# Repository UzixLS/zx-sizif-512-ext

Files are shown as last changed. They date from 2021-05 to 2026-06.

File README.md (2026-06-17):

## Sizif-512 extension

Extension board for [Sizif-512](https://github.com/UzixLS/zx-sizif-512).



### Features
* Turbo Sound FM
* General Sound (12MHz / 512Kb RAM)
* SAA1099
* MIDI sound

### Changelog & current status
* Rev.A - first release. Please note the [errata](pcb/rev.A/ERRATA.txt).
* Rev.A1 - fixed all known issues of rev.A. Please note the [errata](pcb/rev.A1/ERRATA.txt).

### Related projects
* Turbo Sound FM ([link](http://www.nedopc.com/TURBOSOUND/ts-fm.php))
* ZXM-SoundCard ([link](http://micklab.ru/My%20Soundcard/ZXMSoundCard.htm))
* ZXM-GeneralSound ([link](http://micklab.ru/My%20Soundcard/ZXMGeneralSound.htm))

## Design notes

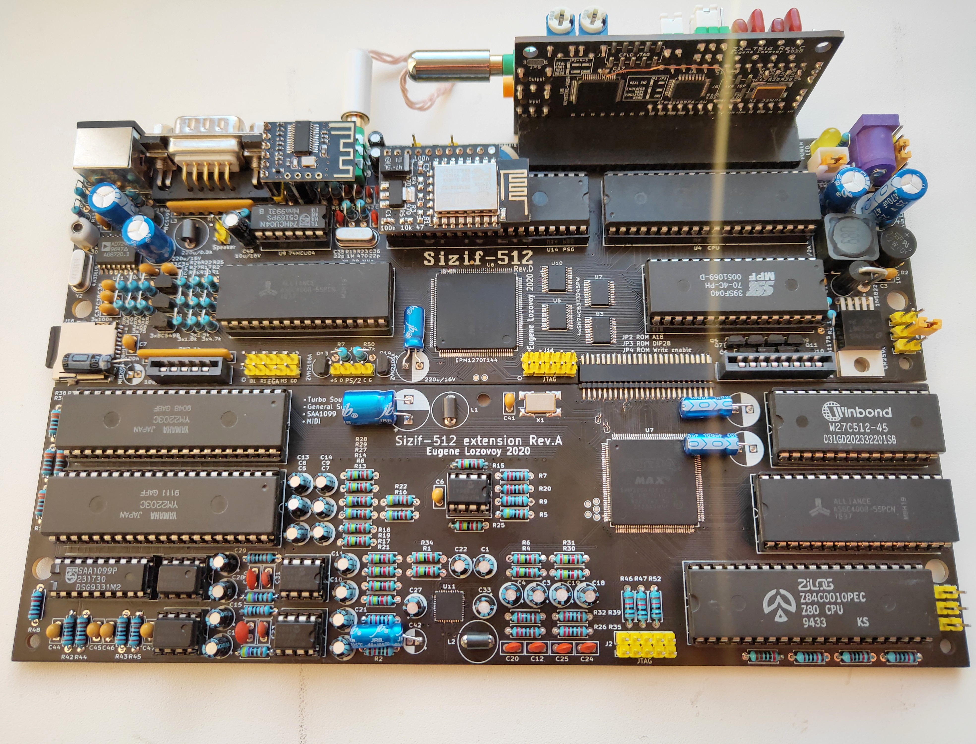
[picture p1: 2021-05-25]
images/revA.jpg

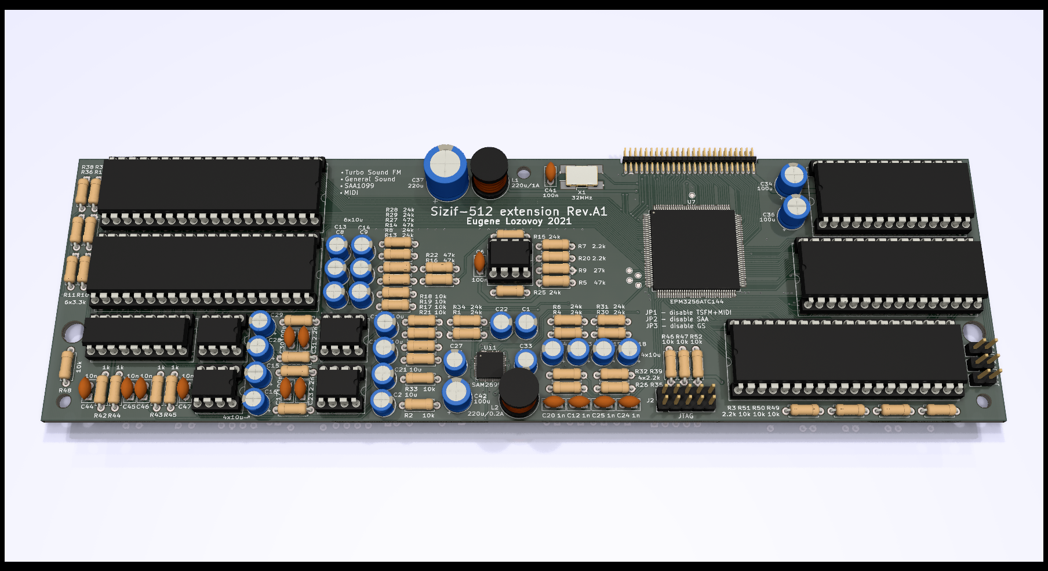
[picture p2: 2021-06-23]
out/pcb3d.rev.A1.png

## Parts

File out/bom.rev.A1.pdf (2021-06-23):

Designator | Package | Designation | Quantity
C23,C31 | C_Disc_D5.0mm_W2.5mm_P2.50mm | 2.2n | 2
C24,C25,C12,C20 | C_Disc_D5.0mm_W2.5mm_P2.50mm | 1n | 4
C30,C41,C17,C6,C60,C62,C39,C65,C40,C67,C61, C64,C63,C66,C38 | C_Disc_D5.0mm_W2.5mm_P2.50mm | 100n | 15
C36,C34,C42 | CP_Radial_D6.3mm_P2.50mm | 100u | 3
C37 | CP_Radial_D10.0mm_P5.00mm | 220u | 1
C4,C13,C9,C8,C10,C7,C21,C14,C5,C3,C27,C33,C1 6,C28,C29,C2,C19,C18,C22,C1,C11,C15 | CP_Radial_D5.0mm_P2.00mm | 10u | 22
C47,C44,C45,C46 | C_Disc_D5.0mm_W2.5mm_P2.50mm | 10n | 4
C49,C51,C52,C53,C54,C56,C57,C58,C59,C26,C68 ,C70,C43,C71,C32,C48,C35,C50,C69,C55 | C_0805_2012Metric_Pad1.15x1.40mm_HandSold er | 100n | 20
J1 | PinHeader_2x25_P1.27mm_Edge_SMD | Conn_02x25_Odd_Even | 1
J2 | PinHeader_2x05_P2.54mm_Vertical | PinHeader | 1
JP1,JP2,JP3 | PinHeader_1x02_P2.54mm_Vertical | Jumper / Pin header 1x2 Pitch=2.54mm | 3
L1 | L_Radial_D8.7mm_P5.00mm_Fastron_07HCP | 220u/1A | 1
L2 | L_Radial_D8.7mm_P5.00mm_Fastron_07HCP | 220u/0.2A | 1
R22,R27,R14,R16,R5 | R_Axial_DIN0207_L6.3mm_D2.5mm_P7.62mm_H orizontal | 47k | 5
R29,R28,R8,R13,R6,R4,R31,R30,R25,R1,R34,R15 | R_Axial_DIN0207_L6.3mm_D2.5mm_P7.62mm_H orizontal | 24k | 12
R3,R20,R35,R39,R7,R32,R26 | R_Axial_DIN0207_L6.3mm_D2.5mm_P7.62mm_H orizontal | 2.2k | 7
R37,R12,R10,R36,R38,R11 | R_Axial_DIN0207_L6.3mm_D2.5mm_P7.62mm_H orizontal | 3.3k | 6
R41,R24 | R_Axial_DIN0207_L6.3mm_D2.5mm_P7.62mm_H orizontal | 470 | 2
R45,R44,R43,R23,R40,R42 | R_Axial_DIN0207_L6.3mm_D2.5mm_P7.62mm_H orizontal | 1k | 6
R48,R19,R21,R33,R47,R52,R2,R17,R18,R49,R50, R51,R46 | R_Axial_DIN0207_L6.3mm_D2.5mm_P7.62mm_H orizontal | 10k | 13
R9 | R_Axial_DIN0207_L6.3mm_D2.5mm_P7.62mm_H orizontal | 27k | 1
U11 | QFN-48-1EP_6x6mm_P0.4mm_EP4.2x4.2mm | SAM2695 | 1
U12 | DIP-32_W15.24mm_Socket | AS6C4008-55PCN | 1
U13 | SOT-223-3_TabPin2 | AMS1117-3.3 | 1
U14 | DIP-18_W7.62mm_Socket | SAA1099 | 1
U2,U1,U6 | DIP-8_W7.62mm_Socket | MCP602 | 3
U3 | DIP-40_W15.24mm_Socket | Z84C0020PEC | 1
U5,U10 | DIP-8_W7.62mm_Socket | YM3014B | 2
U7 | TQFP-144_20x20mm_P0.5mm | EPM3256ATC144 | 1
U8 | DIP-28_W15.24mm_Socket | 27C512 | 1
U9,U4 | DIP-40_W15.24mm_Socket | YM2203 | 2
X1 | Oscillator_SMD_EuroQuartz_XO91-4Pin_7.0x5.0mm_HandSoldering | 32MHz | 1

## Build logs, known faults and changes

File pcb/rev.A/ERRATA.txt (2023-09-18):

- MIDI_IN is connected to U4/pin13, should be U4/pin14
- Incorrect ZX BUS pinout. Following signal pairs should be swapped: NMI/MIX_R, MIX_L/RST, CLKCPU/A1
- Incorrect connection between U5/pin4, U10/pin4 and U7/pin28. Should be cutted.

UPD. 2023-09-18:
- R1 and R34 should be 10kOhm

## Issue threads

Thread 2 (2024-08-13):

Ferrite beads x Fastrons

arleybls, 2024-08-13:
The assembled board image shows what looks like ferrite beads instead of the listed part on the BOM for L1 and L2. Are those alternatives for the Fastrons. Why not list the alternatives as well? If that is not the case can you share the part used on the assembled board image?

UzixLS, 2024-08-14:
For these circuits L1 and L2 values doesn't really matter.

arleybls, 2024-08-14:
Oo..so you say I could just short them? Or put any ferrite bead value? :)

arleybls, 2024-09-06:
is the current rating 1A or also diesnt maater? (can i just shot?)

Closed 2024-08-26.

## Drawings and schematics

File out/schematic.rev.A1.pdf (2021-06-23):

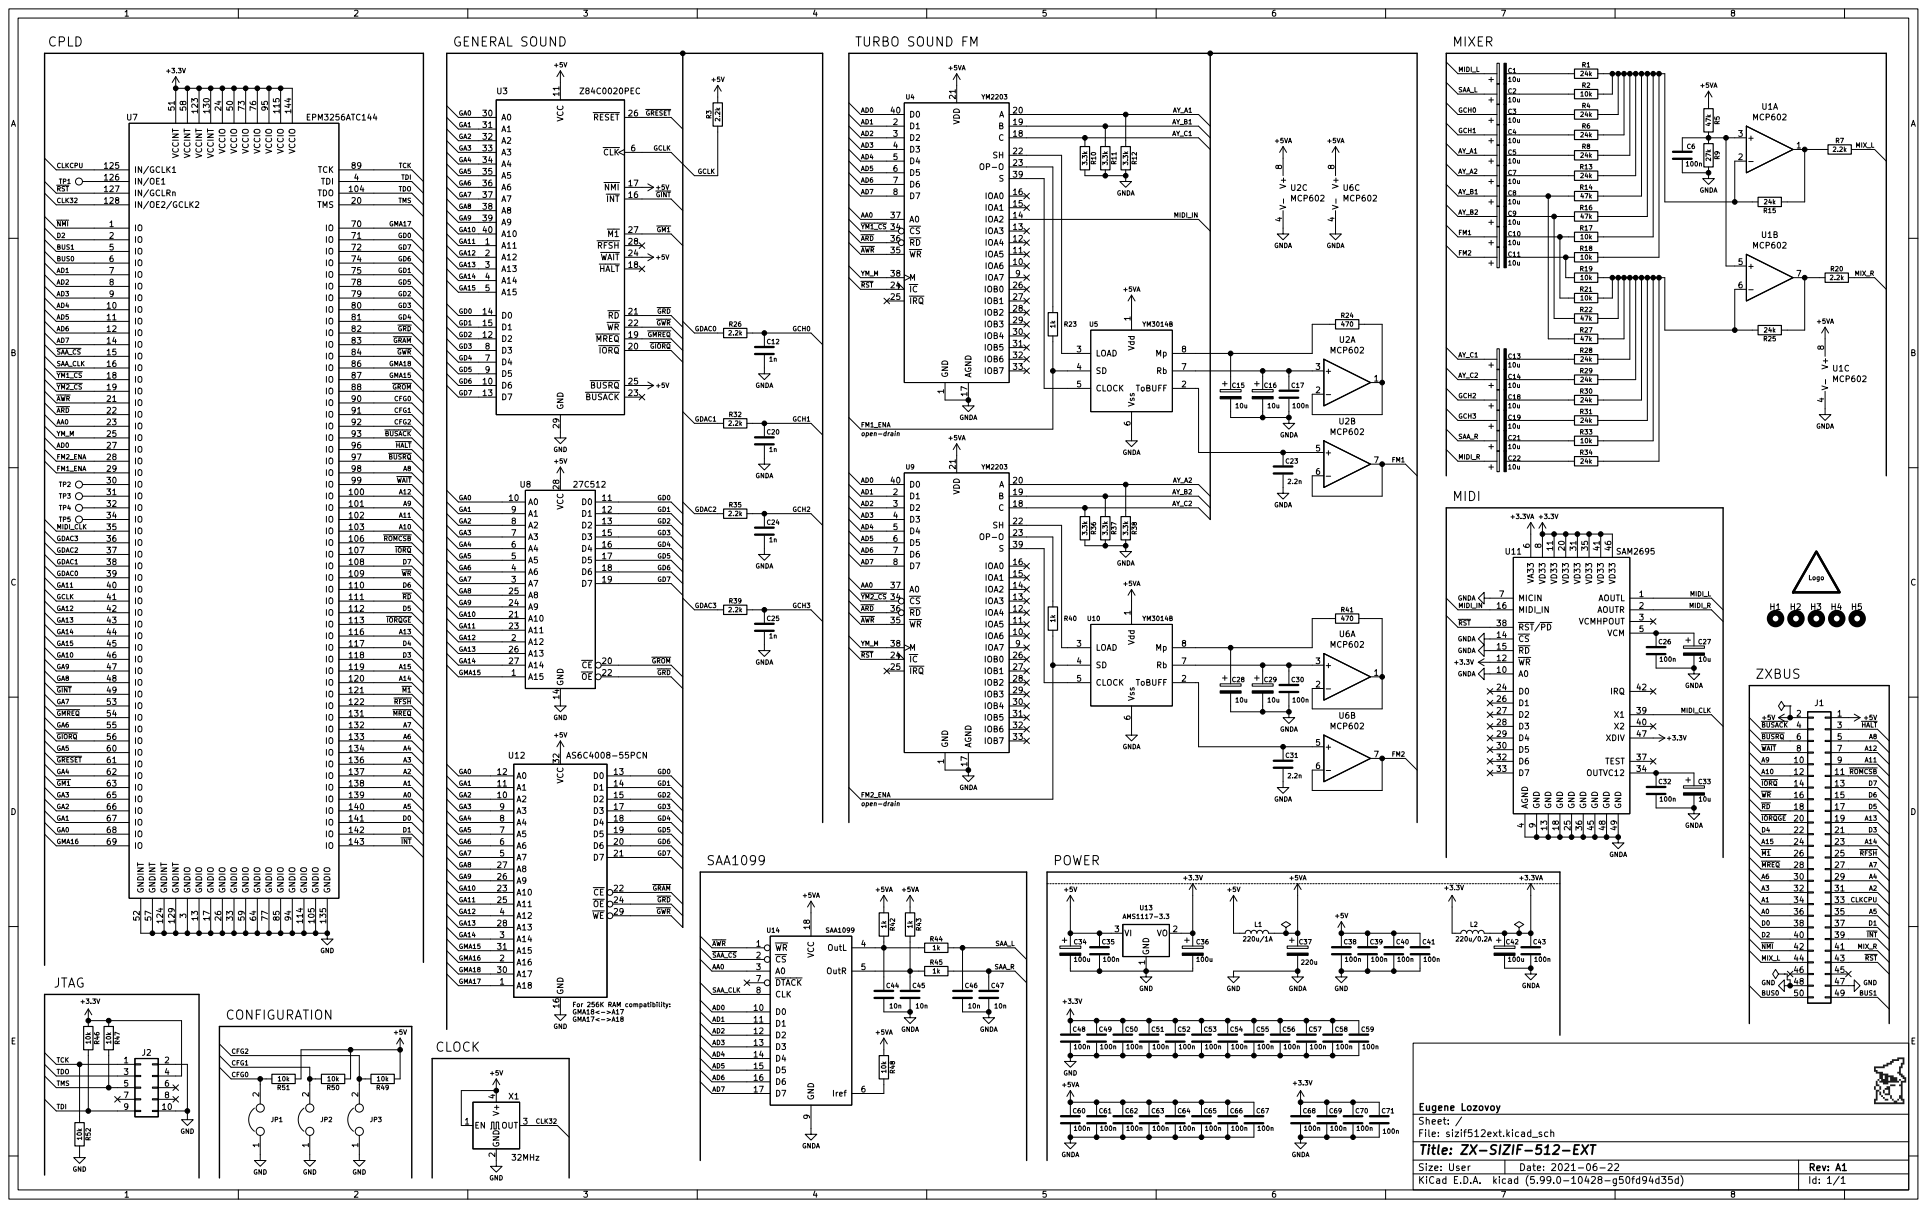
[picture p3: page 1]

1 ToBUFF 2
File: sizif512ext.kicad_sch Sheet: / Eugene Lozovoy Vdd

Id: 1/1 Title: ZX-SIZIF-512-EXT

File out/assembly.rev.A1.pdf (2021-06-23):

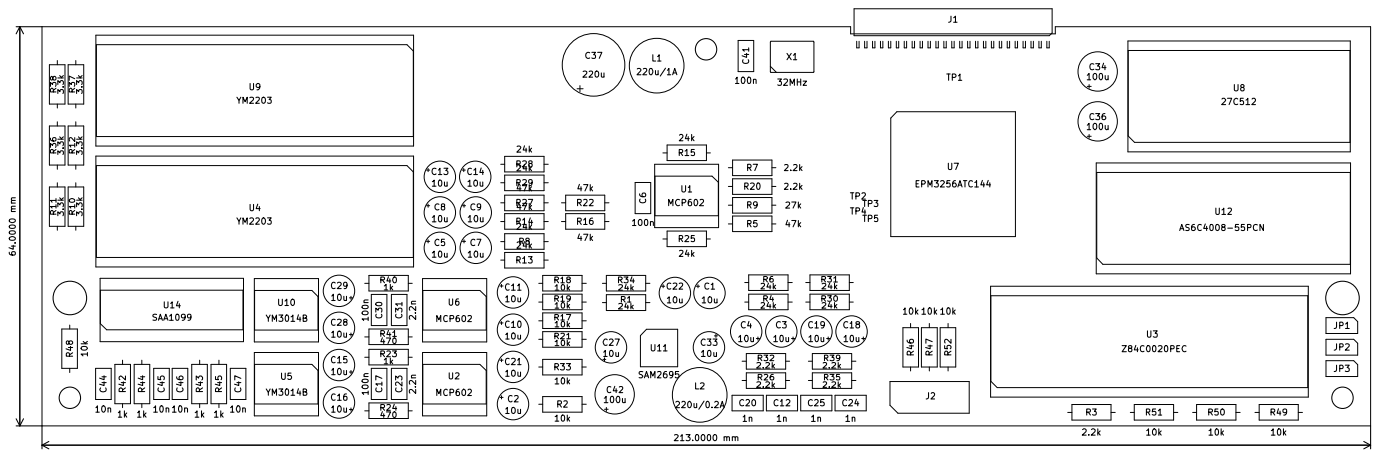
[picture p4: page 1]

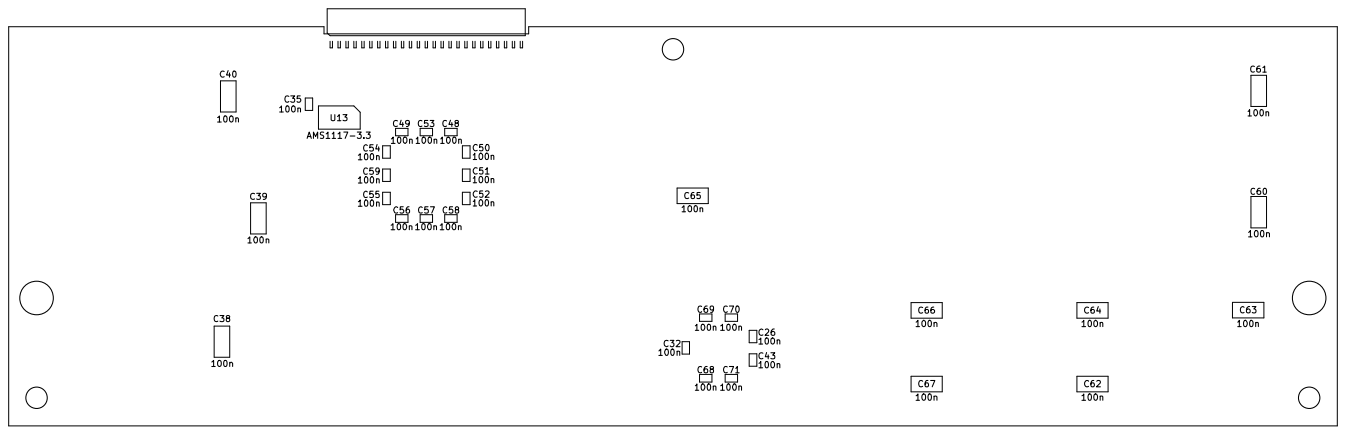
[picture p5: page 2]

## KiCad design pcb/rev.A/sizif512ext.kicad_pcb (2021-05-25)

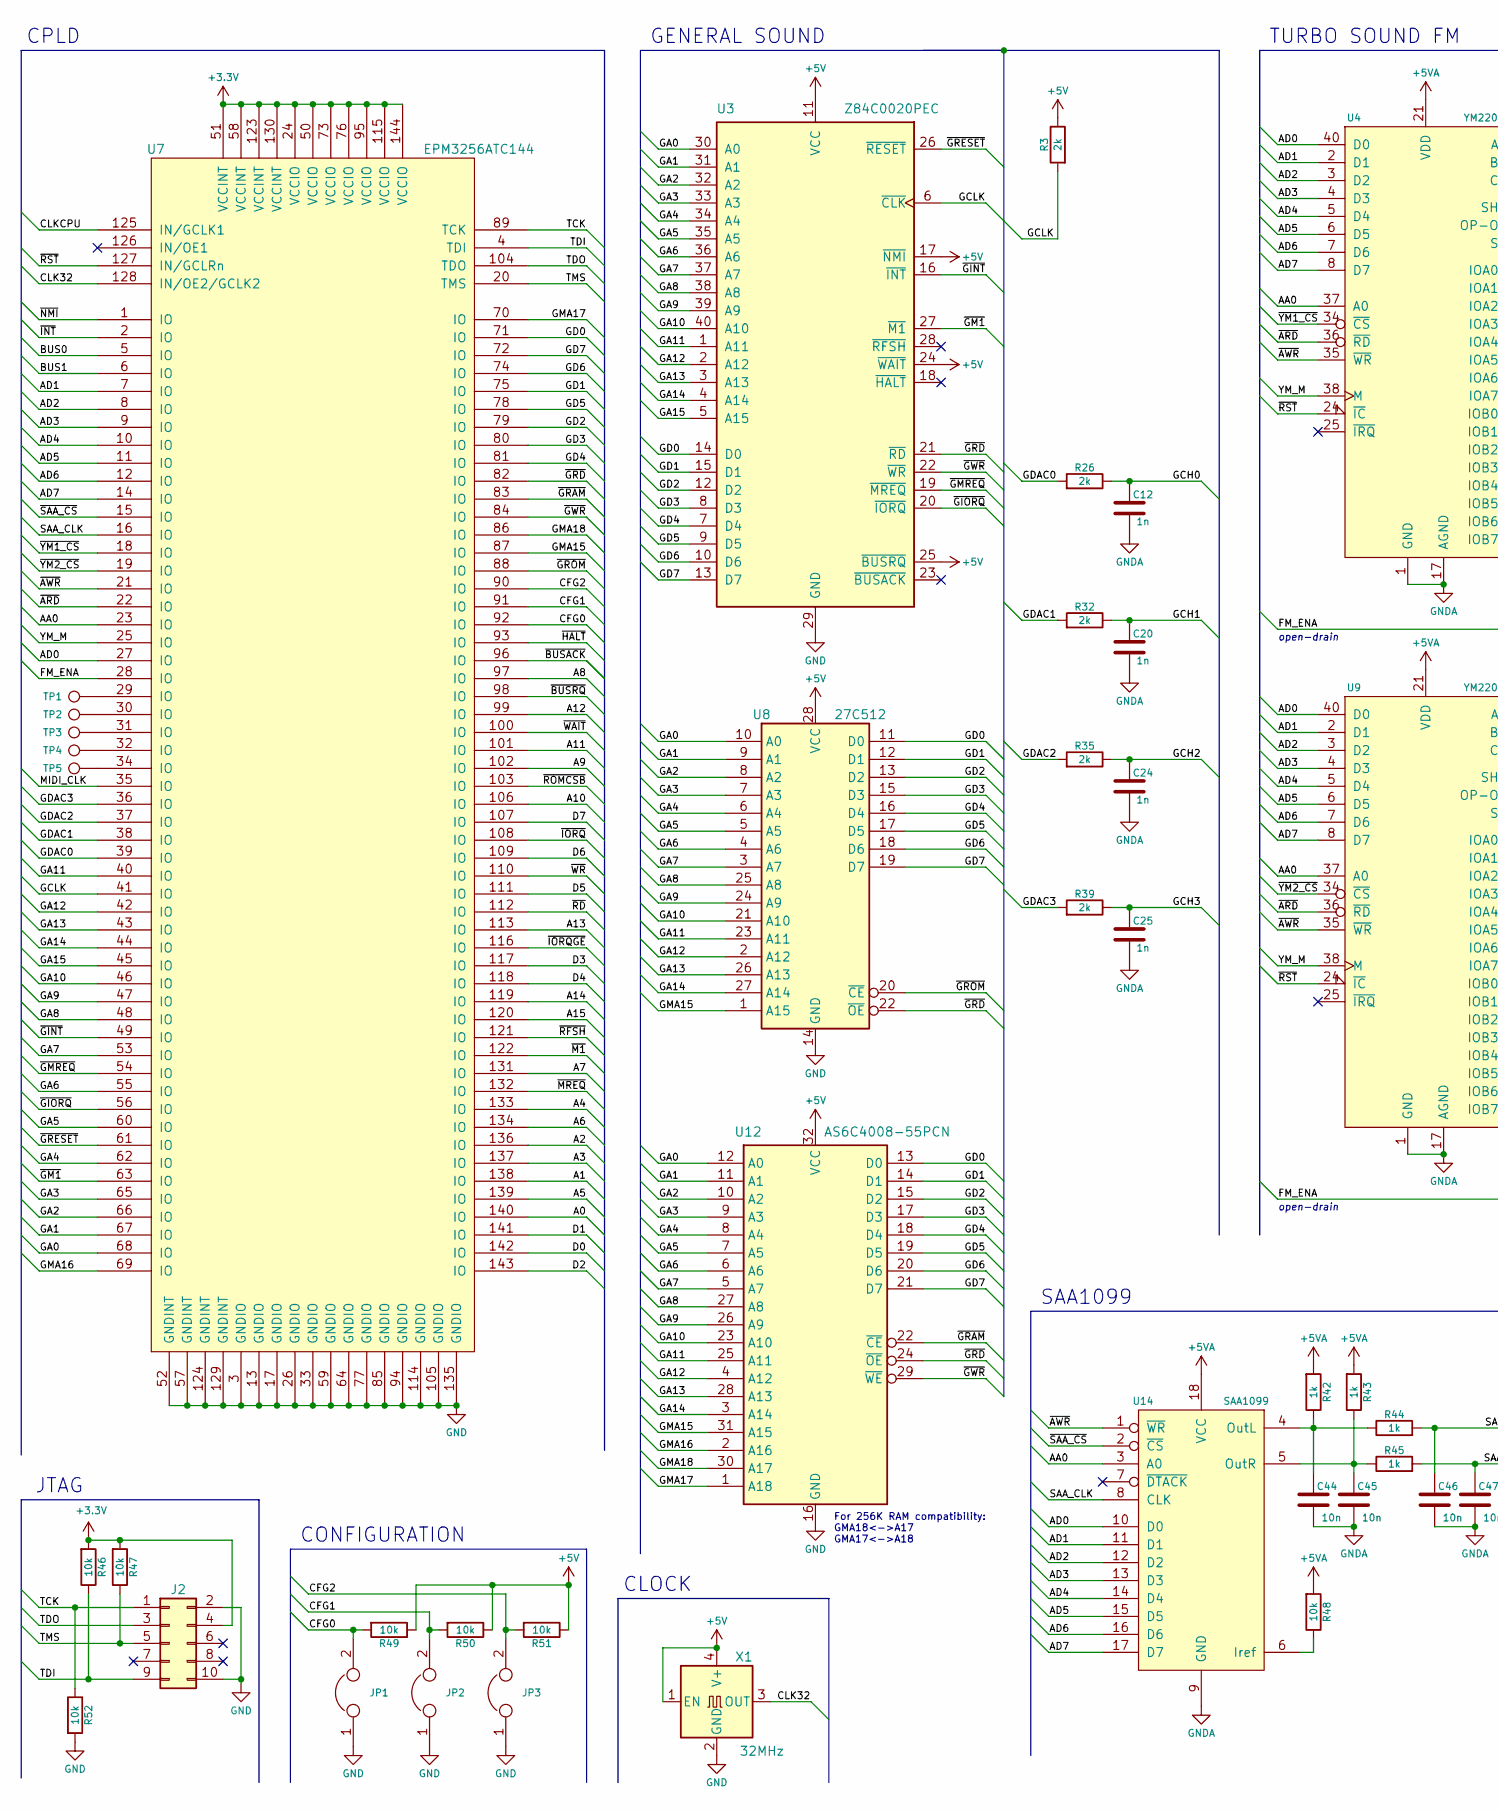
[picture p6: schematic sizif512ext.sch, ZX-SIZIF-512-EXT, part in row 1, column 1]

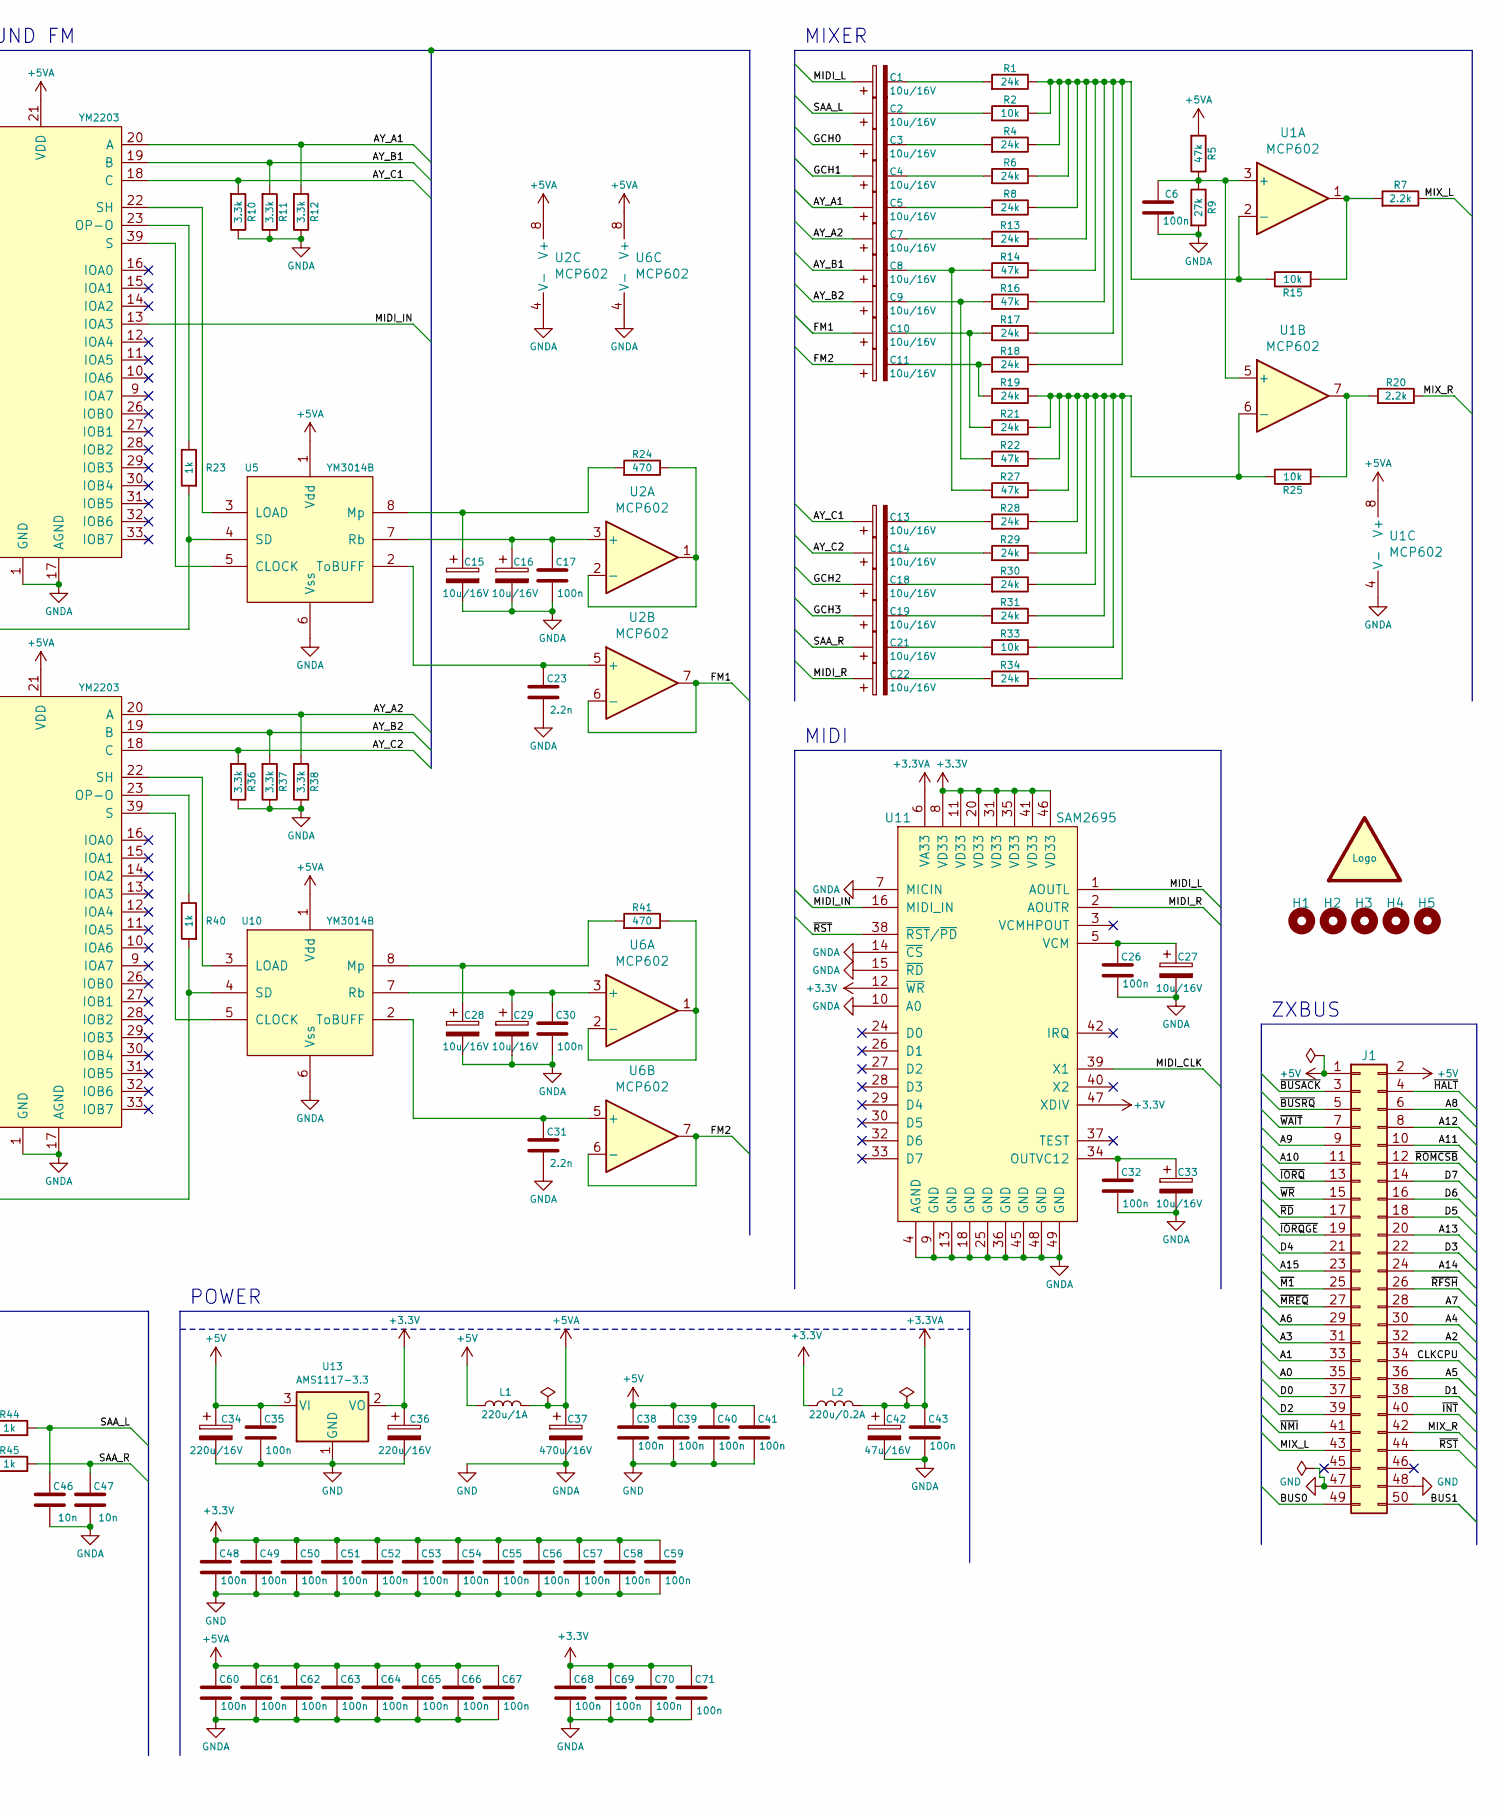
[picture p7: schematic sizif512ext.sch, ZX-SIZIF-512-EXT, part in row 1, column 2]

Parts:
C1, C2, C3, C4, C5, C7, C8, C9, C10, C11, C13, C14, C15, C16, C18, C19, C21, C22, C27, C28, C29, C33: 10u/16V; CP_Radial_D5.0mm_P2.00mm
C6, C17, C30, C38, C39, C40, C41, C60, C61, C62, C63, C64, C65, C66, C67: 100n; C_Disc_D5.0mm_W2.5mm_P2.50mm
C12, C20, C24, C25: 1n; C_Disc_D5.0mm_W2.5mm_P2.50mm
C23, C31: 2.2n; C_Disc_D5.0mm_W2.5mm_P2.50mm
C26, C32, C35, C43, C48, C49, C50, C51, C52, C53, C54, C55, C56, C57, C58, C59, C68, C69, C70, C71: 100n; C_0805_2012Metric_Pad1.15x1.40mm_HandSolder
C34, C36: 220u/16V; CP_Radial_D8.0mm_P3.50mm
C37: 470u/16V; CP_Radial_D10.0mm_P5.00mm
C42: 47u/16V; CP_Radial_D5.0mm_P2.00mm
C44, C45, C46, C47: 10n; C_Disc_D5.0mm_W2.5mm_P2.50mm
H1, H2: MountingHole; MountingHole_5mm_7mm_fence
H3, H4, H5: MountingHole; MountingHole_3mm
J1: Conn_02x25_Odd_Even; PinHeader_2x25_P1.27mm_Edge_SMD
J2: PinHeader; PinHeader_2x05_P2.54mm_Vertical
JP1, JP2, JP3: Jumper / Pin header 1x2 Pitch=2.54mm; PinHeader_1x02_P2.54mm_Vertical
L1: 220u/1A; L_Radial_D8.7mm_P5.00mm_Fastron_07HCP
L2: 220u/0.2A; L_Radial_D8.7mm_P5.00mm_Fastron_07HCP
LOGO1: graphic; black-mage2
R1, R4, R6, R8, R13, R17, R18, R19, R21, R28, R29, R30, R31, R34: 24k; R_Axial_DIN0207_L6.3mm_D2.5mm_P7.62mm_Horizontal
R2, R15, R25, R33, R46, R47, R48, R49, R50, R51, R52: 10k; R_Axial_DIN0207_L6.3mm_D2.5mm_P7.62mm_Horizontal
R3, R26, R32, R35, R39: 2k; R_Axial_DIN0207_L6.3mm_D2.5mm_P7.62mm_Horizontal
R5, R14, R16, R22, R27: 47k; R_Axial_DIN0207_L6.3mm_D2.5mm_P7.62mm_Horizontal
R7, R20: 2.2k; R_Axial_DIN0207_L6.3mm_D2.5mm_P7.62mm_Horizontal
R9: 27k; R_Axial_DIN0207_L6.3mm_D2.5mm_P7.62mm_Horizontal
R10, R11, R12, R36, R37, R38: 3.3k; R_Axial_DIN0207_L6.3mm_D2.5mm_P7.62mm_Horizontal
R23, R40, R42, R43, R44, R45: 1k; R_Axial_DIN0207_L6.3mm_D2.5mm_P7.62mm_Horizontal
R24, R41: 470; R_Axial_DIN0207_L6.3mm_D2.5mm_P7.62mm_Horizontal
TP1, TP2, TP3, TP4, TP5: TestPoint; TestPoint_Pad_D1.0mm
U1, U2, U6: MCP602; DIP-8_W7.62mm_Socket
U3: Z84C0020PEC; DIP-40_W15.24mm_Socket
U4, U9: YM2203; DIP-40_W15.24mm_Socket
U5, U10: YM3014B; DIP-8_W7.62mm_Socket
U7: EPM3256ATC144; TQFP-144_20x20mm_P0.5mm
U8: 27C512; DIP-28_W15.24mm_Socket
U11: SAM2695; QFN-48-1EP_6x6mm_P0.4mm_EP4.2x4.2mm
U12: AS6C4008-55PCN; DIP-32_W15.24mm_Socket
U13: AMS1117-3.3; SOT-223-3_TabPin2
U14: SAA1099; DIP-18_W7.62mm_Socket
X1: 32MHz; Oscillator_SMD_EuroQuartz_XO91-4Pin_7.0x5.0mm_HandSoldering

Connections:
+3.3VA: C42.1, C43.1, L2.2, U11.6 (VA33)
+3V3: C36.1, C48.1, C49.1, C50.1, C51.1, C52.1, C53.1, C54.1, C55.1, C56.1, C57.1, C58.1, C59.1, C68.1, C69.1, C70.1, C71.1, J2.4, L2.1, R46.2, R47.2, U7.24 (VCCIO), U7.50 (VCCIO), U7.51 (VCCINT), U7.58 (VCCINT), U7.73 (VCCIO), U7.76 (VCCIO), U7.95 (VCCIO), U7.115 (VCCIO), U7.123 (VCCINT), U7.130 (VCCINT), U7.144 (VCCIO), U11.8 (VD33), U11.11 (VD33), U11.12 (~WR), U11.20 (VD33), U11.31 (VD33), U11.35 (VD33), U11.41 (VD33), U11.46 (VD33), U11.47 (XDIV), U13.2 (VO)
+5V: C34.1, C35.2, C38.2, C39.2, C40.2, C41.2, J1.1, J1.2, L1.1, R3.1, R49.1, R50.1, R51.1, U3.11 (VCC), U3.17 (~NMI~), U3.24 (~WAIT~), U3.25 (~BUSRQ~), U8.28 (VCC), U12.32 (VCC), U13.3 (VI), X1.1 (EN), X1.4 (V+)
+5VA: C37.1, C60.2, C61.2, C62.2, C63.2, C64.2, C65.2, C66.2, C67.2, L1.2, R5.2, R42.2, R43.2, R48.2, U1.8 (V+), U2.8 (V+), U4.21 (VDD), U5.1 (Vdd), U6.8 (V+), U9.21 (VDD), U10.1 (Vdd), U14.18 (VCC)
/A0: J1.35, U7.140 (IO)
/A1: J1.33, U7.138 (IO)
/A2: J1.32, U7.136 (IO)
/A3: J1.31, U7.137 (IO)
/A4: J1.30, U7.133 (IO)
/A5: J1.36, U7.139 (IO)
/A6: J1.29, U7.134 (IO)
/A7: J1.28, U7.131 (IO)
/A8: J1.6, U7.97 (IO)
/A9: J1.9, U7.102 (IO)
/A10: J1.11, U7.106 (IO)
/A11: J1.10, U7.101 (IO)
/A12: J1.8, U7.99 (IO)
/A13: J1.20, U7.113 (IO)
/A14: J1.24, U7.119 (IO)
/A15: J1.23, U7.120 (IO)
/AA0: U4.37 (A0), U7.23 (IO), U9.37 (A0), U14.3 (A0)
/AD0: U4.40 (D0), U7.27 (IO), U9.40 (D0), U14.10 (D0)
/AD1: U4.2 (D1), U7.7 (IO), U9.2 (D1), U14.11 (D1)
/AD2: U4.3 (D2), U7.8 (IO), U9.3 (D2), U14.12 (D2)
/AD3: U4.4 (D3), U7.9 (IO), U9.4 (D3), U14.13 (D3)
/AD4: U4.5 (D4), U7.10 (IO), U9.5 (D4), U14.14 (D4)
/AD5: U4.6 (D5), U7.11 (IO), U9.6 (D5), U14.15 (D5)
/AD6: U4.7 (D6), U7.12 (IO), U9.7 (D6), U14.16 (D6)
/AD7: U4.8 (D7), U7.14 (IO), U9.8 (D7), U14.17 (D7)
/AY_A1: C5.1, R12.2, U4.20 (A)
/AY_A2: C7.1, R38.2, U9.20 (A)
/AY_B1: C8.1, R11.2, U4.19 (B)
/AY_B2: C9.1, R37.2, U9.19 (B)
/AY_C1: C13.1, R10.2, U4.18 (C)
/AY_C2: C14.1, R36.2, U9.18 (C)
/BUS0: J1.49, U7.5 (IO)
/BUS1: J1.50, U7.6 (IO)
/CFG0: JP1.2, R49.2, U7.92 (IO)
/CFG1: JP2.2, R50.2, U7.91 (IO)
/CFG2: JP3.2, R51.2, U7.90 (IO)
/CLK32: U7.128 (IN/OE2/GCLK2), X1.3 (OUT)
/CLKCPU: J1.34, U7.125 (IN/GCLK1)
/D0: J1.37, U7.142 (IO)
/D1: J1.38, U7.141 (IO)
/D2: J1.39, U7.143 (IO)
/D3: J1.22, U7.117 (IO)
/D4: J1.21, U7.118 (IO)
/D5: J1.18, U7.111 (IO)
/D6: J1.16, U7.109 (IO)
/D7: J1.14, U7.107 (IO)
/FM1: C10.1, U2.6 (-), U2.7
/FM2: C11.1, U6.6 (-), U6.7
/FM_ENA: R23.2, R40.2, U5.4 (SD), U7.28 (IO), U10.4 (SD)
/GA0: U3.30 (A0), U7.68 (IO), U8.10 (A0), U12.12 (A0)
/GA1: U3.31 (A1), U7.67 (IO), U8.9 (A1), U12.11 (A1)
/GA2: U3.32 (A2), U7.66 (IO), U8.8 (A2), U12.10 (A2)
/GA3: U3.33 (A3), U7.65 (IO), U8.7 (A3), U12.9 (A3)
/GA4: U3.34 (A4), U7.62 (IO), U8.6 (A4), U12.8 (A4)
/GA5: U3.35 (A5), U7.60 (IO), U8.5 (A5), U12.7 (A5)
/GA6: U3.36 (A6), U7.55 (IO), U8.4 (A6), U12.6 (A6)
/GA7: U3.37 (A7), U7.53 (IO), U8.3 (A7), U12.5 (A7)
/GA8: U3.38 (A8), U7.48 (IO), U8.25 (A8), U12.27 (A8)
/GA9: U3.39 (A9), U7.47 (IO), U8.24 (A9), U12.26 (A9)
/GA10: U3.40 (A10), U7.46 (IO), U8.21 (A10), U12.23 (A10)
/GA11: U3.1 (A11), U7.40 (IO), U8.23 (A11), U12.25 (A11)
/GA12: U3.2 (A12), U7.42 (IO), U8.2 (A12), U12.4 (A12)
/GA13: U3.3 (A13), U7.43 (IO), U8.26 (A13), U12.28 (A13)
/GA14: U3.4 (A14), U7.44 (IO), U8.27 (A14), U12.3 (A14)
/GA15: U3.5 (A15), U7.45 (IO)
/GCH0: C3.1, C12.1, R26.1
/GCH1: C4.1, C20.1, R32.1
/GCH2: C18.1, C24.1, R35.1
/GCH3: C19.1, C25.1, R39.1
/GCLK: R3.2, U3.6 (~CLK~), U7.41 (IO)
/GD0: U3.14 (D0), U7.71 (IO), U8.11 (D0), U12.13 (D0)
/GD1: U3.15 (D1), U7.75 (IO), U8.12 (D1), U12.14 (D1)
/GD2: U3.12 (D2), U7.79 (IO), U8.13 (D2), U12.15 (D2)
/GD3: U3.8 (D3), U7.80 (IO), U8.15 (D3), U12.17 (D3)
/GD4: U3.7 (D4), U7.81 (IO), U8.16 (D4), U12.18 (D4)
/GD5: U3.9 (D5), U7.78 (IO), U8.17 (D5), U12.19 (D5)
/GD6: U3.10 (D6), U7.74 (IO), U8.18 (D6), U12.20 (D6)
/GD7: U3.13 (D7), U7.72 (IO), U8.19 (D7), U12.21 (D7)
/GDAC0: R26.2, U7.39 (IO)
/GDAC1: R32.2, U7.38 (IO)
/GDAC2: R35.2, U7.37 (IO)
/GDAC3: R39.2, U7.36 (IO)
/GMA15: U7.87 (IO), U8.1 (A15), U12.31 (A15)
/GMA16: U7.69 (IO), U12.2 (A16)
/GMA17: U7.70 (IO), U12.1 (A18)
/GMA18: U7.86 (IO), U12.30 (A17)
/MIDI_CLK: U7.35 (IO), U11.39 (X1)
/MIDI_IN: U4.13 (IOA3), U11.16 (MIDI_IN)
/MIDI_L: C1.1, U11.1 (AOUTL)
/MIDI_R: C22.1, U11.2 (AOUTR)
/MIX_L: J1.43, R7.1
/MIX_R: J1.42, R20.1
/SAA_CLK: U7.16 (IO), U14.8 (CLK)
/SAA_L: C2.1, C46.1, R44.2
/SAA_R: C21.1, C47.1, R45.2
/TCK: J2.1, R52.1, U7.89 (TCK)
/TDI: J2.9, R46.1, U7.4 (TDI)
/TDO: J2.3, U7.104 (TDO)
/TMS: J2.5, R47.1, U7.20 (TMS)
/YM_M: U4.38 (M), U7.25 (IO), U9.38 (M)
/~ARD: U4.36 (~RD~), U7.22 (IO), U9.36 (~RD~)
/~AWR: U4.35 (~WR~), U7.21 (IO), U9.35 (~WR~), U14.1 (~WR)
/~BUSACK: J1.3, U7.96 (IO)
/~BUSRQ: J1.5, U7.98 (IO)
/~GINT: U3.16 (~INT~), U7.49 (IO)
/~GIORQ: U3.20 (~IORQ~), U7.56 (IO)
/~GM1: U3.27 (~M1~), U7.63 (IO)
/~GMREQ: U3.19 (~MREQ~), U7.54 (IO)
/~GRAM: U7.83 (IO), U12.22 (~CE)
/~GRD: U3.21 (~RD~), U7.82 (IO), U8.22 (~OE), U12.24 (~OE)
/~GRESET: U3.26 (~RESET~), U7.61 (IO)
/~GROM: U7.88 (IO), U8.20 (~CE)
/~GWR: U3.22 (~WR~), U7.84 (IO), U12.29 (~WE)
/~HALT: J1.4, U7.93 (IO)
/~INT: J1.40, U7.2 (IO)
/~IORQ: J1.13, U7.108 (IO)
/~IORQGE: J1.19, U7.116 (IO)
/~M1: J1.25, U7.122 (IO)
/~MREQ: J1.27, U7.132 (IO)
/~NMI: J1.41, U7.1 (IO)
/~RD: J1.17, U7.112 (IO)
/~RFSH: J1.26, U7.121 (IO)
/~ROMCSB: J1.12, U7.103 (IO)
/~RST: J1.44, U4.24 (~IC~), U7.127 (IN/GCLRn), U9.24 (~IC~), U11.38 (~RST~/~PD~)
/~SAA_CS: U7.15 (IO), U14.2 (~CS)
/~WAIT: J1.7, U7.100 (IO)
/~WR: J1.15, U7.110 (IO)
/~YM1_CS: U4.34 (~CS~), U7.18 (IO)
/~YM2_CS: U7.19 (IO), U9.34 (~CS~)
GND: C6.1, C12.2, C15.2, C16.2, C17.2, C20.2, C23.2, C24.2, C25.2, C26.2, C27.2, C28.2, C29.2, C30.2, C31.2, C32.2, C33.2, C34.2, C35.1, C36.2, C37.2, C38.1, C39.1, C40.1, C41.1, C42.2, C43.2, C44.2, C45.2, C46.2, C47.2, C48.2, C49.2, C50.2, C51.2, C52.2, C53.2, C54.2, C55.2, C56.2, C57.2, C58.2, C59.2, C60.1, C61.1, C62.1, C63.1, C64.1, C65.1, C66.1, C67.1, C68.2, C69.2, C70.2, C71.2, J1.47, J1.48, J2.2, J2.10, JP1.1, JP2.1, JP3.1, R9.2, R10.1, R11.1, R12.1, R36.1, R37.1, R38.1, R52.2, U1.4 (V-), U2.4 (V-), U3.29 (GND), U4.1 (GND), U4.17 (AGND), U5.6 (Vss), U6.4 (V-), U7.3 (GNDIO), U7.13 (GNDIO), U7.17 (GNDIO), U7.26 (GNDIO), U7.33 (GNDIO), U7.52 (GNDINT), U7.57 (GNDINT), U7.59 (GNDIO), U7.64 (GNDIO), U7.77 (GNDIO), U7.85 (GNDIO), U7.94 (GNDIO), U7.105 (GNDIO), U7.114 (GNDIO), U7.124 (GNDINT), U7.129 (GNDINT), U7.135 (GNDIO), U8.14 (GND), U9.1 (GND), U9.17 (AGND), U10.6 (Vss), U11.4 (AGND), U11.7 (MICIN), U11.9 (GND), U11.10 (A0), U11.13 (GND), U11.14 (~CS), U11.15 (~RD), U11.18 (GND), U11.25 (GND), U11.36 (GND), U11.45 (GND), U11.48 (GND), U11.49 (GND), U12.16 (GND), U13.1 (GND), U14.9 (GND), X1.2 (GND)
unnamed: C1.2, R1.2
unnamed: C2.2, R2.2
unnamed: C3.2, R4.2
unnamed: C4.2, R6.2
unnamed: C5.2, R8.2
unnamed: C6.2, R5.1, R9.1, U1.3 (+), U1.5 (+)
unnamed: C7.2, R13.2
unnamed: C8.2, R14.2, R27.2
unnamed: C9.2, R16.2, R22.2
unnamed: C10.2, R17.2, R21.2
unnamed: C11.2, R18.2, R19.2
unnamed: C13.2, R28.2
unnamed: C14.2, R29.2
unnamed: C15.1, R24.2, U5.8 (Mp)
unnamed: C16.1, C17.1, U2.3 (+), U5.7 (Rb)
unnamed: C18.2, R30.2
unnamed: C19.2, R31.2
unnamed: C21.2, R33.2
unnamed: C22.2, R34.2
unnamed: C23.1, U2.5 (+), U5.2 (ToBUFF)
unnamed: C26.1, C27.1, U11.5 (VCM)
unnamed: C28.1, R41.2, U10.8 (Mp)
unnamed: C29.1, C30.1, U6.3 (+), U10.7 (Rb)
unnamed: C31.1, U6.5 (+), U10.2 (ToBUFF)
unnamed: C32.1, C33.1, U11.34 (OUTVC12)
unnamed: C44.1, R42.1, R44.1, U14.4 (OutL)
unnamed: C45.1, R43.1, R45.1, U14.5 (OutR)
unnamed: R1.1, R2.1, R4.1, R6.1, R8.1, R13.1, R14.1, R15.1, R16.1, R17.1, R18.1, U1.2 (-)
unnamed: R7.2, R15.2, U1.1
unnamed: R19.1, R21.1, R22.1, R25.1, R27.1, R28.1, R29.1, R30.1, R31.1, R33.1, R34.1, U1.6 (-)
unnamed: R20.2, R25.2, U1.7
unnamed: R23.1, U4.23 (OP-O)
unnamed: R24.1, U2.1, U2.2 (-)
unnamed: R40.1, U9.23 (OP-O)
unnamed: R41.1, U6.1, U6.2 (-)
unnamed: R48.1, U14.6 (Iref)
unnamed: TP1.1, U7.29 (IO)
unnamed: TP2.1, U7.30 (IO)
unnamed: TP3.1, U7.31 (IO)
unnamed: TP4.1, U7.32 (IO)
unnamed: TP5.1, U7.34 (IO)
unnamed: U4.22 (SH), U5.3 (LOAD)
unnamed: U4.39 (S), U5.5 (CLOCK)
unnamed: U9.22 (SH), U10.3 (LOAD)
unnamed: U9.39 (S), U10.5 (CLOCK)

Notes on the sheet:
JTAG
CLOCK
CPLD
For 256K RAM compatibility: GMA18<->A17 GMA17<->A18
MIXER
TURBO SOUND FM
ZXBUS
POWER
SAA1099
CONFIGURATION
open-drain
GENERAL SOUND
MIDI

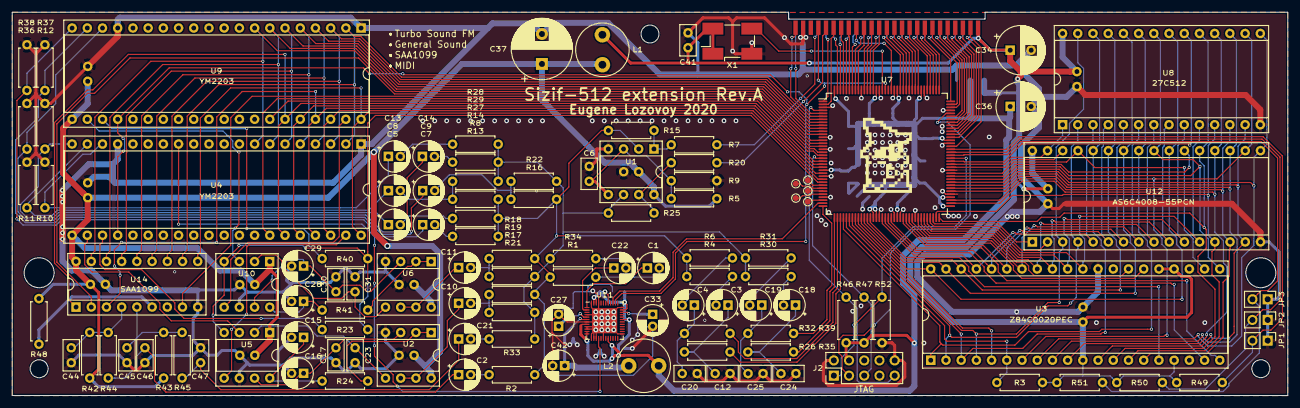
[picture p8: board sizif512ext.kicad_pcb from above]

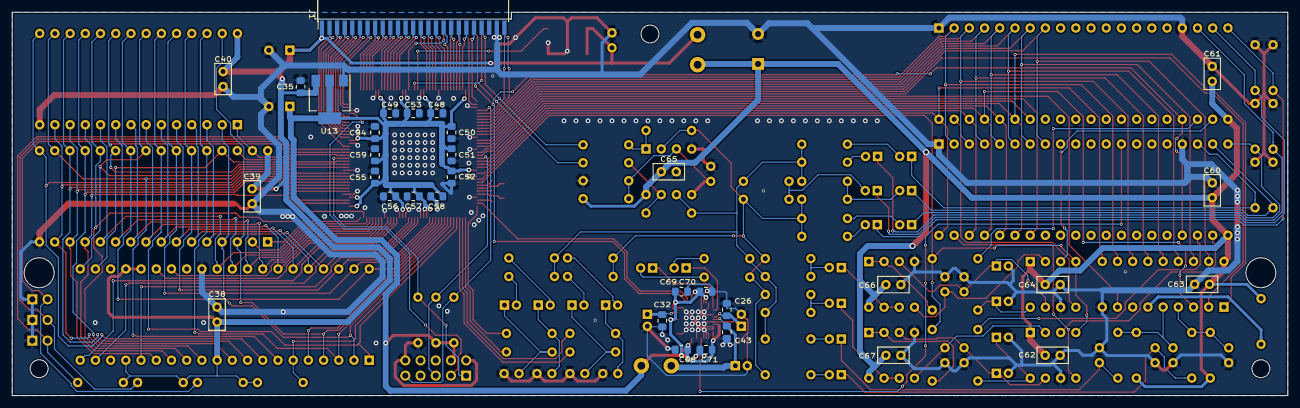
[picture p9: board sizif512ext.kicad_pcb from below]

Board: 2 copper layers, 213.0 x 64.0 mm, 156 parts (33 on the bottom side), 179 nets.

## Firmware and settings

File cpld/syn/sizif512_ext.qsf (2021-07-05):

# -------------------------------------------------------------------------- #
#
# Copyright (C) 1991-2013 Altera Corporation
# Your use of Altera Corporation's design tools, logic functions 
# and other software and tools, and its AMPP partner logic 
# functions, and any output files from any of the foregoing 
# (including device programming or simulation files), and any 
# associated documentation or information are expressly subject 
# to the terms and conditions of the Altera Program License 
# Subscription Agreement, Altera MegaCore Function License 
# Agreement, or other applicable license agreement, including, 
# without limitation, that your use is for the sole purpose of 
# programming logic devices manufactured by Altera and sold by 
# Altera or its authorized distributors.  Please refer to the 
# applicable agreement for further details.
#
# -------------------------------------------------------------------------- #
#
# Quartus II 64-Bit
# Version 13.0.1 Build 232 06/12/2013 Service Pack 1 SJ Full Version
# Date created = 12:04:27  October 04, 2020
#
# -------------------------------------------------------------------------- #
#
# Notes:
#
# 1) The default values for assignments are stored in the file:
#		sizif512_ext_assignment_defaults.qdf
#    If this file doesn't exist, see file:
#		assignment_defaults.qdf
#
# 2) Altera recommends that you do not modify this file. This
#    file is updated automatically by the Quartus II software
#    and any changes you make may be lost or overwritten.
#
# -------------------------------------------------------------------------- #


set_global_assignment -name FAMILY MAX3000A
set_global_assignment -name DEVICE "EPM3256ATC144-10"
set_global_assignment -name TOP_LEVEL_ENTITY sizif512_ext
set_global_assignment -name ORIGINAL_QUARTUS_VERSION "13.0 SP1"
set_global_assignment -name PROJECT_CREATION_TIME_DATE "12:04:27  OCTOBER 04, 2020"
set_global_assignment -name LAST_QUARTUS_VERSION "13.0 SP1"
set_global_assignment -name PROJECT_OUTPUT_DIRECTORY output
set_global_assignment -name DEVICE_FILTER_PIN_COUNT 144
set_global_assignment -name ERROR_CHECK_FREQUENCY_DIVISOR "-1"
set_global_assignment -name MIN_CORE_JUNCTION_TEMP 0
set_global_assignment -name MAX_CORE_JUNCTION_TEMP 85
set_global_assignment -name SDC_FILE clocks.sdc
set_global_assignment -name VERILOG_FILE ../rtl/top.v
set_global_assignment -name VHDL_INPUT_VERSION VHDL_2008
set_global_assignment -name VHDL_SHOW_LMF_MAPPING_MESSAGES OFF
set_global_assignment -name VERILOG_INPUT_VERSION SYSTEMVERILOG_2005
set_global_assignment -name VERILOG_SHOW_LMF_MAPPING_MESSAGES OFF
set_global_assignment -name MAX7000_DEVICE_IO_STANDARD "3.3-V LVTTL"
set_global_assignment -name SAVE_DISK_SPACE OFF
set_global_assignment -name TIMEQUEST_MULTICORNER_ANALYSIS OFF
set_global_assignment -name SYNTH_TIMING_DRIVEN_SYNTHESIS OFF
set_location_assignment PIN_1 -to n_nmi
set_location_assignment PIN_2 -to d[2]
set_location_assignment PIN_5 -to bus1
set_location_assignment PIN_6 -to bus0
set_location_assignment PIN_7 -to ad[1]
set_location_assignment PIN_8 -to ad[2]
set_location_assignment PIN_9 -to ad[3]
set_location_assignment PIN_10 -to ad[4]
set_location_assignment PIN_11 -to ad[5]
set_location_assignment PIN_12 -to ad[6]
set_location_assignment PIN_14 -to ad[7]
set_location_assignment PIN_15 -to n_saa_cs
set_location_assignment PIN_16 -to saa_clk
set_location_assignment PIN_19 -to n_ym2_cs
set_location_assignment PIN_18 -to n_ym1_cs
set_location_assignment PIN_21 -to n_awr
set_location_assignment PIN_22 -to n_ard
set_location_assignment PIN_23 -to aa0
set_location_assignment PIN_25 -to ym_m
set_location_assignment PIN_27 -to ad[0]
set_location_assignment PIN_28 -to fm2_ena
set_location_assignment PIN_29 -to fm1_ena
set_location_assignment PIN_35 -to midi_clk
set_location_assignment PIN_36 -to gdac3
set_location_assignment PIN_37 -to gdac2
set_location_assignment PIN_38 -to gdac1
set_location_assignment PIN_39 -to gdac0
set_location_assignment PIN_40 -to ga[11]
set_location_assignment PIN_41 -to gclk
set_location_assignment PIN_67 -to ga[1]
set_location_assignment PIN_42 -to ga[12]
set_location_assignment PIN_43 -to ga[13]
set_location_assignment PIN_44 -to ga[14]
set_location_assignment PIN_45 -to ga[15]
set_location_assignment PIN_46 -to ga[10]
set_location_assignment PIN_47 -to ga[9]
set_location_assignment PIN_48 -to ga[8]
set_location_assignment PIN_49 -to n_gint
set_location_assignment PIN_53 -to ga[7]
set_location_assignment PIN_54 -to n_gmreq
set_location_assignment PIN_55 -to ga[6]
set_location_assignment PIN_56 -to n_giorq
set_location_assignment PIN_60 -to ga[5]
set_location_assignment PIN_61 -to n_grst
set_location_assignment PIN_62 -to ga[4]
set_location_assignment PIN_63 -to n_gm1
set_location_assignment PIN_65 -to ga[3]
set_location_assignment PIN_66 -to ga[2]
set_location_assignment PIN_68 -to ga[0]
set_location_assignment PIN_69 -to gma[16]
set_location_assignment PIN_70 -to gma[17]
set_location_assignment PIN_71 -to gd[0]
set_location_assignment PIN_72 -to gd[7]
set_location_assignment PIN_74 -to gd[6]
set_location_assignment PIN_75 -to gd[1]
set_location_assignment PIN_78 -to gd[5]
set_location_assignment PIN_79 -to gd[2]
set_location_assignment PIN_80 -to gd[3]
set_location_assignment PIN_81 -to gd[4]
set_location_assignment PIN_82 -to n_grd
set_location_assignment PIN_83 -to n_gram
set_location_assignment PIN_84 -to n_gwr
set_location_assignment PIN_86 -to gma[18]
set_location_assignment PIN_87 -to gma[15]
set_location_assignment PIN_88 -to n_grom
set_location_assignment PIN_90 -to cfg[0]
set_location_assignment PIN_91 -to cfg[1]
set_location_assignment PIN_92 -to cfg[2]
set_location_assignment PIN_93 -to n_busack
set_location_assignment PIN_96 -to n_halt
set_location_assignment PIN_97 -to n_busrq
set_location_assignment PIN_98 -to a[8]
set_location_assignment PIN_99 -to n_wait
set_location_assignment PIN_100 -to a[12]
set_location_assignment PIN_101 -to a[9]
set_location_assignment PIN_102 -to a[11]
set_location_assignment PIN_103 -to a[10]
set_location_assignment PIN_106 -to n_romcsb
set_location_assignment PIN_107 -to n_iorq
set_location_assignment PIN_108 -to d[7]
set_location_assignment PIN_109 -to n_wr
set_location_assignment PIN_110 -to d[6]
set_location_assignment PIN_111 -to n_rd
set_location_assignment PIN_112 -to d[5]
set_location_assignment PIN_113 -to n_iorqge
set_location_assignment PIN_116 -to a[13]
set_location_assignment PIN_117 -to d[4]
set_location_assignment PIN_118 -to d[3]
set_location_assignment PIN_119 -to a[15]
set_location_assignment PIN_120 -to a[14]
set_location_assignment PIN_121 -to n_m1
set_location_assignment PIN_122 -to n_rfsh
set_location_assignment PIN_131 -to n_mreq
set_location_assignment PIN_132 -to a[7]
set_location_assignment PIN_133 -to a[6]
set_location_assignment PIN_134 -to a[4]
set_location_assignment PIN_136 -to a[3]
set_location_assignment PIN_137 -to a[2]
set_location_assignment PIN_138 -to a[1]
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

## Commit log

2021-05-25 add pcb rev.A
    [sizif512ext.kicad_pcb, sizif512ext.sch]
2021-06-23 add pcb rev.A1
    [sizif512ext.kicad_sch]
2021-06-23 add gerbers and etc. for pcb rev.A1
2021-07-09 update gerbers for rev.A1
2023-09-18 update errata for pcb rev.A and rev.A1
